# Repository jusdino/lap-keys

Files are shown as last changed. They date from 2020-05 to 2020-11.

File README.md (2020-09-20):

# lap-keys
A keyboard design that allows hands to naturally rest on the lap, while using

## Overview
This is a design prototype in progress for a new keyboard that will hopefully fix some ergonomic issues with my desk at home. Namely, I'm sick of keeping my hands up on a desk all day. I'd much rather let them relax on my lap while I work. Nothing I can find for commercially available (or other build-your-own) keyboard/mouse units seem to fit the bill.

## Prototypes
**Split Sixty Wedge**
- This is the first prototype I'm working on that is intended to be 'lap-friendly'. It should receive the custom PCBs I've designed to each include 5 switches in a column and a header that sticks out the top to allow for hand-wiring the key matrix between columns. This prototype is designed to be a simple 5x12 rectilinear split keyboard with each half arranged into a forward-pointing wedge. This configuration should get your wrists into a sensible orientation while typing either on a desk or your lap. It also includes a trackball, to help reduce the need for a dedicated pointing device. I'm calling this first prototype the **split sixty wedge**:
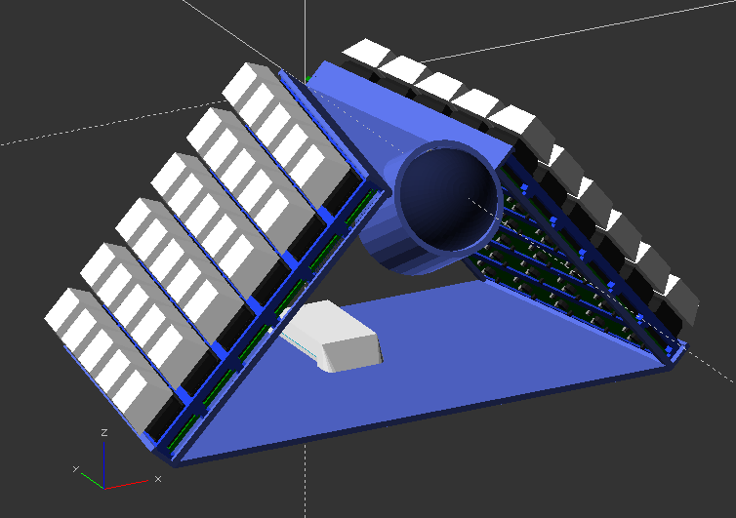
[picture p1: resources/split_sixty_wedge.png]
split sixty wedge


## Prints
The prints section of this repo consists of [OpenScad](https://www.openscad.org/) modules for any prototyping I'm doing and some that allow for quick definition of a keyboard with little more than the coordinates of where you want keys to be located. I've thrown together some *brain_storming* layouts with just coordinates that still produced a part that was reasonably printable, if not polished-looking. 

Some of the OpenScad modules include:

- Any prototypes I'm currently working on
- A rough mock-up of a CherryMX switch:
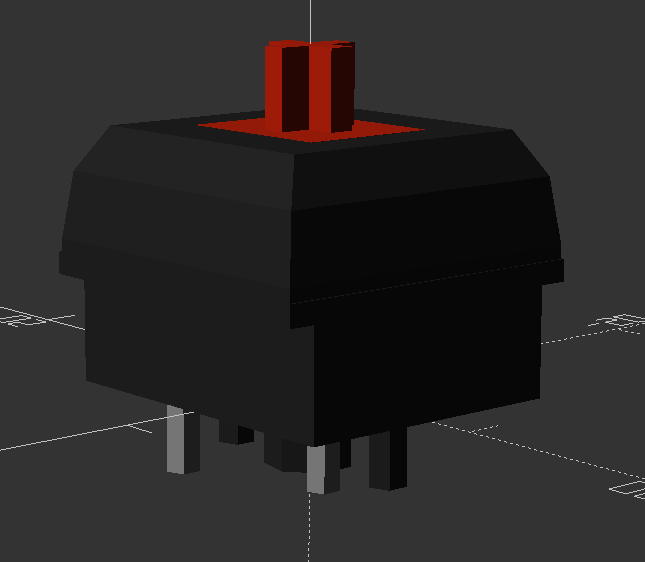
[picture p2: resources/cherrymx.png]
cherrymx switch


**Brain storming modules** that can be used for quick brain storming of layout ideas and can potentially be printed out and hand-wired:
- Sockets to fit the CherryMX switch:
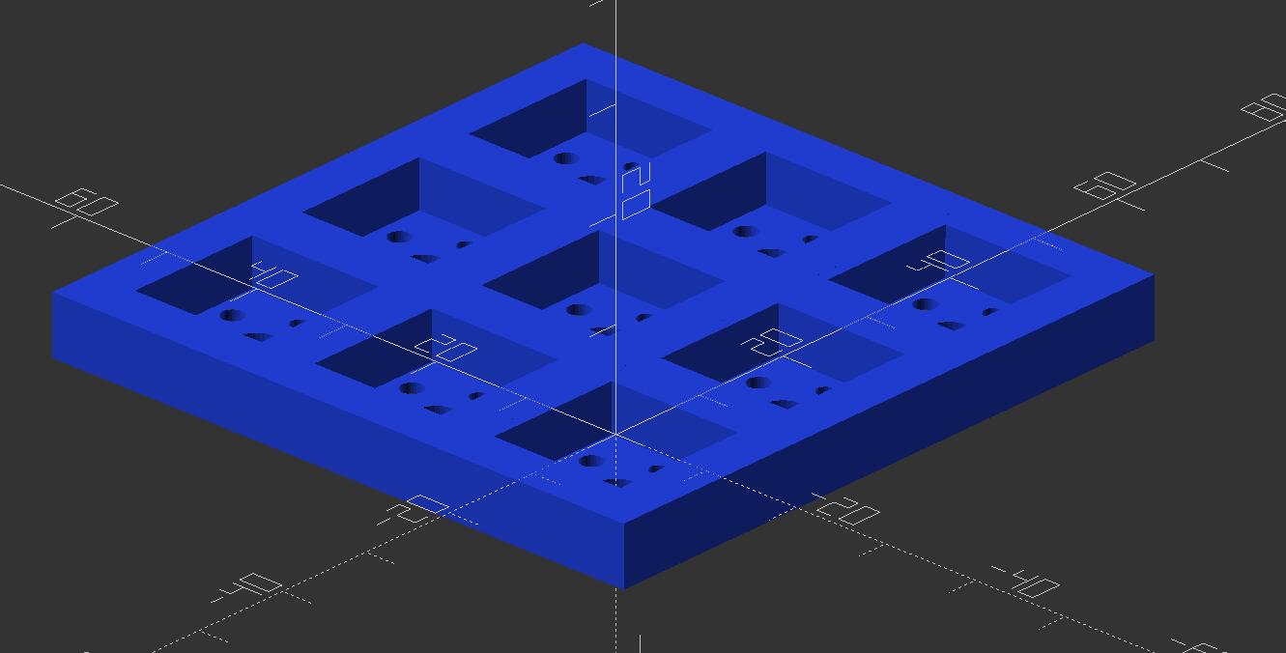
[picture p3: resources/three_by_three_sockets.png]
cherrymx socket


- A base to hold the sockets with space underneath for wiring:
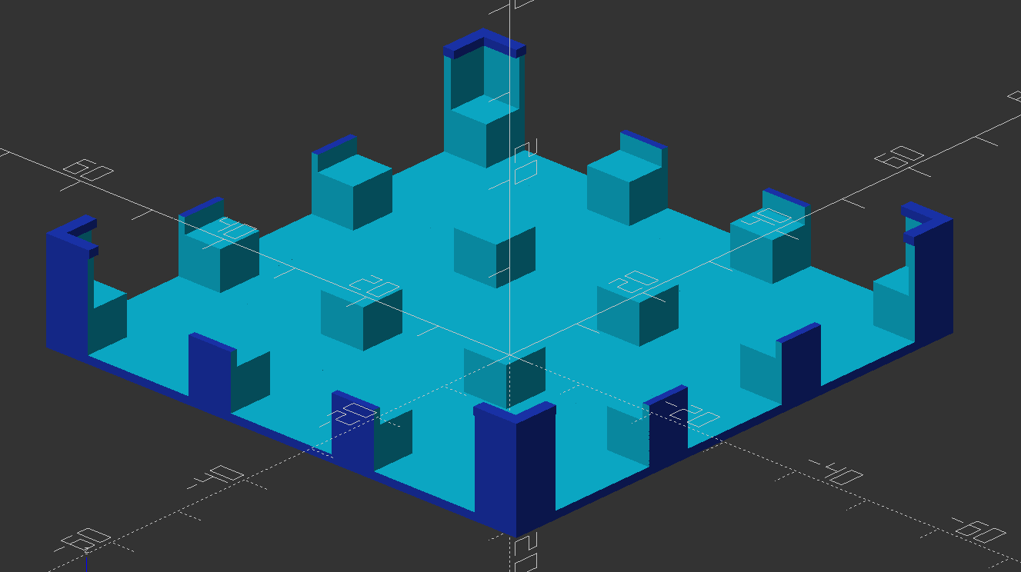
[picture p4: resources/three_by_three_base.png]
cherrymx base


- Some utility modules that can take a set of coordinates and translate them into the start of a workable keyboard:
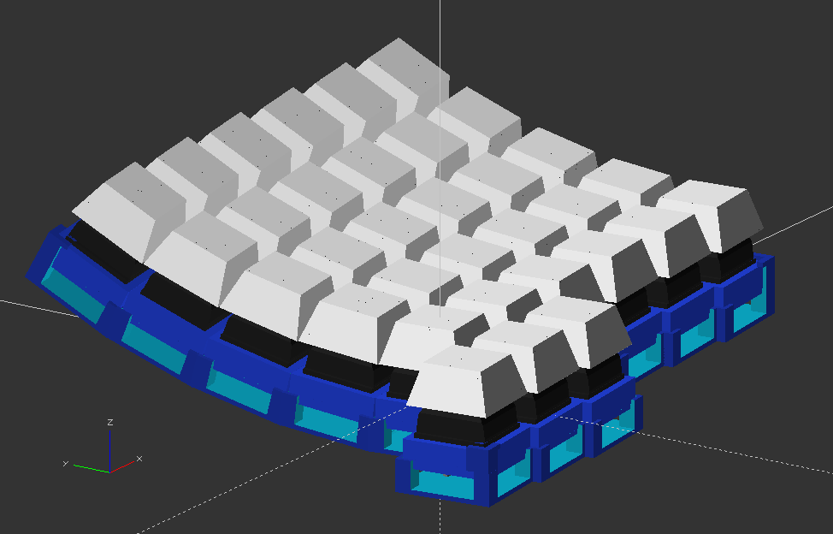
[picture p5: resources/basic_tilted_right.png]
tilted ortho


## Firmware
The firmware section of this repo contains MicroController Unit firmware I've designed to run on the MCU that drives the keyboard prototypes. These firmwares use the [QMK firmware](https://qmk.fm/) as their base.

## PCBs
The pcbs section of the repo contains KiCad PCB design files for any PCBs I design as part of this project

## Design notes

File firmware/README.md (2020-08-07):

# Keyboard Firmware

This firmware has been developed to use the [QMK Framework](https://docs.qmk.fm/#/) to program the MicroController Unit (MCU) that drives the keyboards in this repo. To use these firmware versions, copy (or softlink) the named keyboard directories into the QMK repository under `keyboards` and use them as described in the QMK documentation.

Keyboard firmwares:

## lap_keys
This firmware will drive the 60-key (5x12) keyboards in this project. The versions are:
- **v0.1**:
  Written for an [Elite-C MCU](https://keeb.io/products/elite-c-low-profile-version-usb-c-pro-micro-replacement-atmega32u4). Just keys. Very basic firmware with the keymap I worked out for the **split-sixty-percent** board.
- **v0.2**:
  Written for an [Elite-C MCU](https://keeb.io/products/elite-c-low-profile-version-usb-c-pro-micro-replacement-atmega32u4). Introduces the driver for the PMW3360 sensor used for a trackball.
- **v0.3**:
  Written for a [Proton-C MCU](https://qmk.fm/proton-c/). Same features as v0.2.

## 3_by_3
Firmware to test out a quick numpad-like prototype for learning purposes

## right_sixty_percent
Firmware to test out half of a sixty-percent keyboard

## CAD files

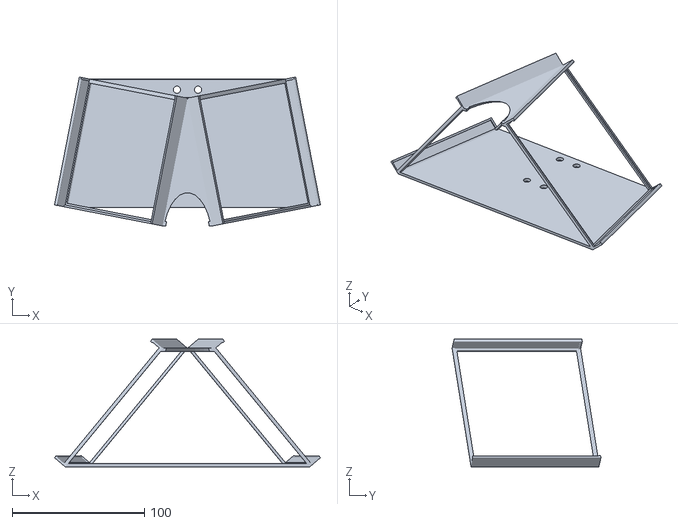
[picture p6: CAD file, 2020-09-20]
prints/outputs/split_sixty_wedge_base.stl
201.2 x 112.6 x 96.4

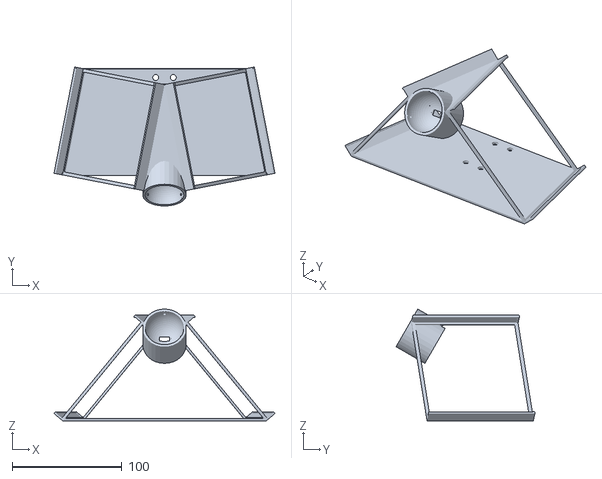
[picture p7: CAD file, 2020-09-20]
prints/outputs/split_sixty_wedge_base_w_trackball.stl
201.2 x 126.5 x 101.9

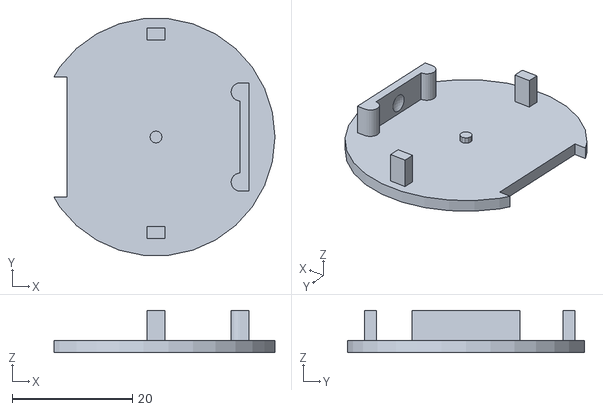
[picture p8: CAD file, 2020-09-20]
prints/outputs/trackball_mount_backing.stl
36.8 x 39.4 x 6.99

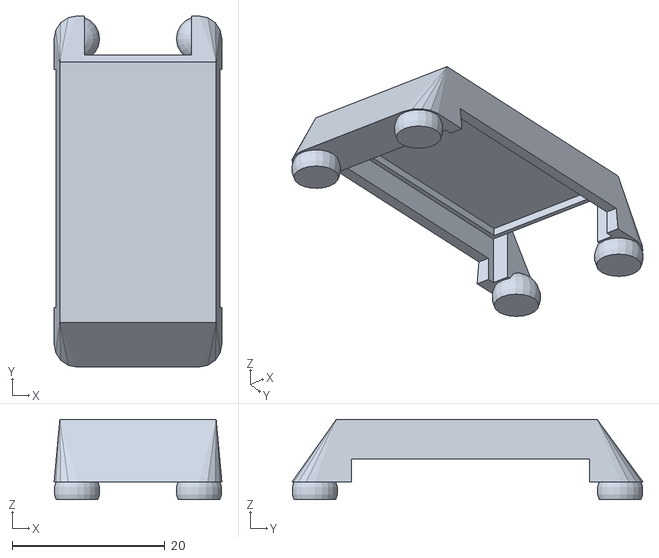
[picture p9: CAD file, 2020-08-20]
prints/outputs/split_sixty_wedge_elite_c_mount_top.stl
22.0 x 46.0 x 10.5

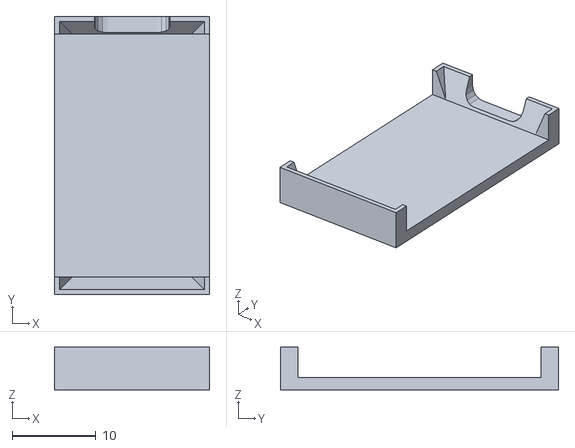
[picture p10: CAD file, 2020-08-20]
prints/outputs/split_sixty_wedge_elite_c_mount_bottom.stl
18.5 x 33.2 x 5.10

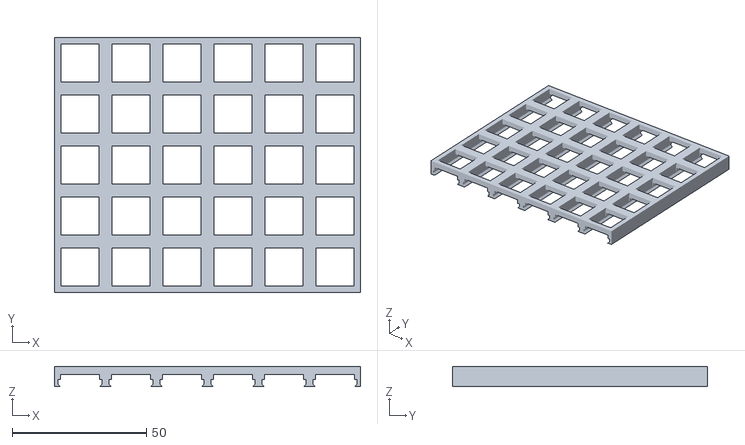
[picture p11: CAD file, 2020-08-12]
prints/outputs/split_sixty_wedge_plate.stl
114.0 x 95.0 x 7.60

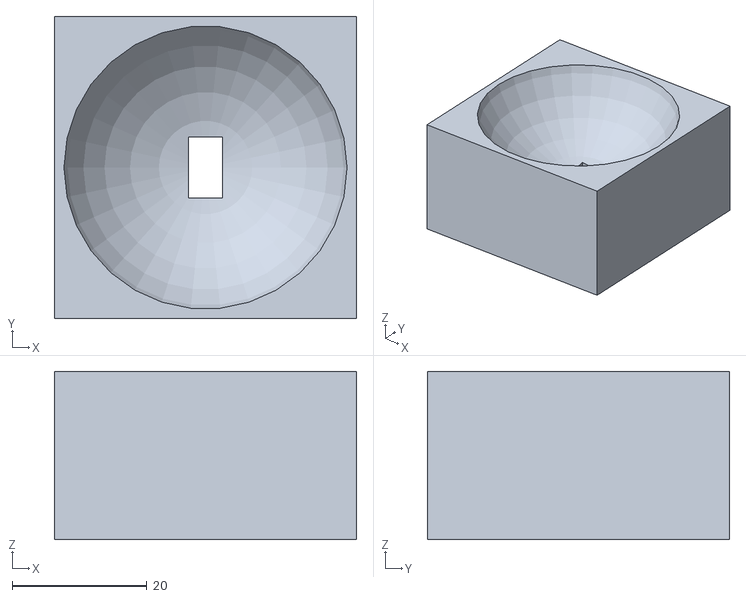
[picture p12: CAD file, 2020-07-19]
prints/outputs/track_stand.stl
44.8 x 44.8 x 24.9

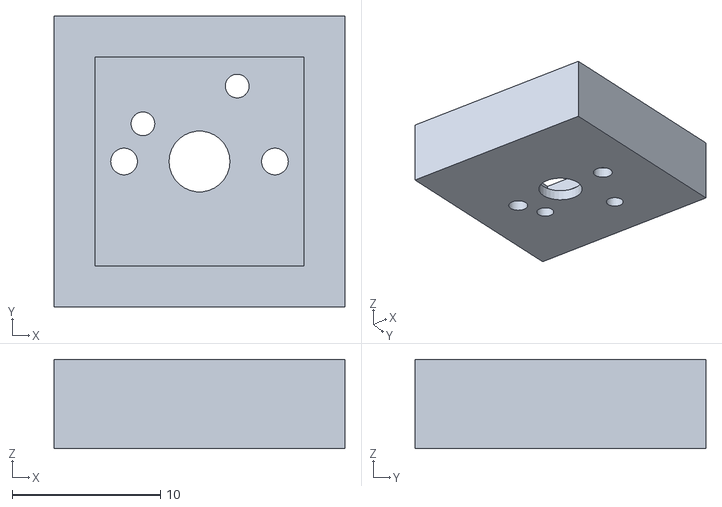
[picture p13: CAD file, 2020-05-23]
prints/outputs/cherrymx_socket.stl
19.6 x 19.6 x 6.00

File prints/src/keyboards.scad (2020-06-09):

include <switches.scad>;
include <sockets.scad>;
include <keycaps.scad>;
include <abstractions.scad>;
include <bases.scad>;

flat_ortho_grid(
  x_count=6,
  y_count=5,
  spacing=19,
  sockets=true,
  pcb_pins=true);

module sixty_percent(pcb_pins=false) {
  flat_ortho_grid(12, 5, pcb_pins);
}

module split_sixty_percent(pcb_pins=false) {
  flat_ortho_grid(6, 5, pcb_pins);
}

module three_by_three(pcb_pins=false) {
  flat_ortho_grid(3, 3, keys_and_caps=true, sockets=true, base=true, pcb_pins=pcb_pins);
}

module basic_ortholinear_right(pcb_pins=false) {
  spacing = 20;
  coords = [
    [0, 0, 0], [1, 0, 0], [2, 0, 0], [0, 1, 0], [0, 2, 0], [0, 3, 0], [0, 4, 0],
    [1, 1, 0], [2, 1, 0], [3, 1, 0], [4, 1, 0], [5, 1, 0], [6, 1, 0],
    [1, 2, 0], [2, 2, 0], [3, 2, 0], [4, 2, 0], [5, 2, 0], [6, 2, 0],
    [1, 3, 0], [2, 3, 0], [3, 3, 0], [4, 3, 0], [5, 3, 0], [6, 3, 0],
    [1, 4, 0], [2, 4, 0], [3, 4, 0], [4, 4, 0], [5, 4, 0], [6, 4, 0],
  ];

  dimensions = spacing * coords;

  map_over_xyz(dimensions) {
    keycap_1u();
    cherrymx(pcb_pins);
    cherrymx_socket(pcb_pins);
  }
  difference() {
    map_over_xyz(dimensions) {
      cherrymx_base_positive();
    }
    map_over_xyz(dimensions) {
      cherrymx_base_negative();
    }
  }
}

module basic_tilted_right(pcb_pins=false) {
  key_spacing = 20;
  curve_x_rad = 150;
  arc_length = key_spacing;
  dphi = (360*arc_length)/(2*PI*curve_x_rad);
  function y_from_phi(phi) = sin(phi)*curve_x_rad;
  function z_from_phi(phi) = curve_x_rad * (1 - cos(phi));
  function dx_from_phi(phi) = 2*phi/dphi;
  theta = atan(2/key_spacing);
  coords = [
  // X                                  Y                   Z                   PHI,    THETA
    [0,                                 -key_spacing,       0,                  0,      theta],
    [key_spacing,                       -key_spacing,       0,                  0,      theta],
    [0*key_spacing-dx_from_phi(0),      y_from_phi(0),      z_from_phi(0),      0,      theta],
    [1*key_spacing-dx_from_phi(0),      y_from_phi(0),      z_from_phi(0),      0,      theta],
    [2*key_spacing-dx_from_phi(0),      y_from_phi(0),      z_from_phi(0),      0,      theta],
    [3*key_spacing-dx_from_phi(0),      y_from_phi(0),      z_from_phi(0),      0,      theta],
    [4*key_spacing-dx_from_phi(0),      y_from_phi(0),      z_from_phi(0),      0,      theta],
    [5*key_spacing-dx_from_phi(0),      y_from_phi(0),      z_from_phi(0),      0,      theta],
    [6*key_spacing-dx_from_phi(0),      y_from_phi(0),      z_from_phi(0),      0,      theta],
    [0*key_spacing-dx_from_phi(1*dphi), y_from_phi(1*dphi), z_from_phi(1*dphi), 1*dphi, theta],
    [1*key_spacing-dx_from_phi(1*dphi), y_from_phi(1*dphi), z_from_phi(1*dphi), 1*dphi, theta],
    [2*key_spacing-dx_from_phi(1*dphi), y_from_phi(1*dphi), z_from_phi(1*dphi), 1*dphi, theta],
    [3*key_spacing-dx_from_phi(1*dphi), y_from_phi(1*dphi), z_from_phi(1*dphi), 1*dphi, theta],
    [4*key_spacing-dx_from_phi(1*dphi), y_from_phi(1*dphi), z_from_phi(1*dphi), 1*dphi, theta],
    [5*key_spacing-dx_from_phi(1*dphi), y_from_phi(1*dphi), z_from_phi(1*dphi), 1*dphi, theta],
    [6*key_spacing-dx_from_phi(1*dphi), y_from_phi(1*dphi), z_from_phi(1*dphi), 1*dphi, theta],
    [0*key_spacing-dx_from_phi(2*dphi), y_from_phi(2*dphi), z_from_phi(2*dphi), 2*dphi, theta],
    [1*key_spacing-dx_from_phi(2*dphi), y_from_phi(2*dphi), z_from_phi(2*dphi), 2*dphi, theta],
    [2*key_spacing-dx_from_phi(2*dphi), y_from_phi(2*dphi), z_from_phi(2*dphi), 2*dphi, theta],
    [3*key_spacing-dx_from_phi(2*dphi), y_from_phi(2*dphi), z_from_phi(2*dphi), 2*dphi, theta],
    [4*key_spacing-dx_from_phi(2*dphi), y_from_phi(2*dphi), z_from_phi(2*dphi), 2*dphi, theta],
    [5*key_spacing-dx_from_phi(2*dphi), y_from_phi(2*dphi), z_from_phi(2*dphi), 2*dphi, theta],
    [6*key_spacing-dx_from_phi(2*dphi), y_from_phi(2*dphi), z_from_phi(2*dphi), 2*dphi, theta],
    [0*key_spacing-dx_from_phi(3*dphi), y_from_phi(3*dphi), z_from_phi(3*dphi), 3*dphi, theta],
    [1*key_spacing-dx_from_phi(3*dphi), y_from_phi(3*dphi), z_from_phi(3*dphi), 3*dphi, theta],
    [2*key_spacing-dx_from_phi(3*dphi), y_from_phi(3*dphi), z_from_phi(3*dphi), 3*dphi, theta],
    [3*key_spacing-dx_from_phi(3*dphi), y_from_phi(3*dphi), z_from_phi(3*dphi), 3*dphi, theta],
    [4*key_spacing-dx_from_phi(3*dphi), y_from_phi(3*dphi), z_from_phi(3*dphi), 3*dphi, theta],
    [5*key_spacing-dx_from_phi(3*dphi), y_from_phi(3*dphi), z_from_phi(3*dphi), 3*dphi, theta],
    [6*key_spacing-dx_from_phi(3*dphi), y_from_phi(3*dphi), z_from_phi(3*dphi), 3*dphi, theta],
  ];
  corners = [
  // X                                  Y                   Z                   PHI,    THETA
    [0,                                 -key_spacing,       0,                  0,      theta],
    [0*key_spacing-dx_from_phi(3*dphi), y_from_phi(3*dphi), z_from_phi(3*dphi), 3*dphi, theta],
    [6*key_spacing-dx_from_phi(3*dphi), y_from_phi(3*dphi), z_from_phi(3*dphi), 3*dphi, theta],
    [6*key_spacing-dx_from_phi(0),      y_from_phi(0),      z_from_phi(0),      0,      theta],
  ];

  map_over_xyzpt(coords) {
    keycap_1u();
    cherrymx(pcb_pins);
    cherrymx_socket(pcb_pins);
  }
  difference() {
    union() {
      map_over_xyzpt(coords) {
        cherrymx_base_positive();
      }
      map_over_xyzpt([corners[0]]) cherrymx_base_corner_clip(minus_x_minus_y=true);
      map_over_xyzpt([corners[1]]) cherrymx_base_corner_clip(minus_x_plus_y=true);
      map_over_xyzpt([corners[2]]) cherrymx_base_corner_clip(plus_x_plus_y=true);
      map_over_xyzpt([corners[3]]) cherrymx_base_corner_clip(plus_x_minus_y=true);
    }
    map_over_xyzpt(coords) {
      cherrymx_base_negative();
    }
  }
}

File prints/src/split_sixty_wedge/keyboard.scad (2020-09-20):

// KEYBOARD: Split Sixty Wedge
// First step towards a more functional design: Adding a PCB, reducing space for hand-wires.

// MULTI-MODULE VARS
// General inputs
keys_and_caps=true;
plates=true;
pcbs=true;

mcu_mount=true;
mcu=true;

trackball_mount=true;
trackball=true;
sensor=true;
bearings=true;

keyboard_x_count = 6;
keyboard_y_count = 5;
keyboard_switch_spacing = 19;
keyboard_y_rotation = 50;
keyboard_z_rotation = 11;

include <switch_plate.scad>;

// switch_base attributes
switch_base_thickness = 1.5;
switch_base_bottom_width = 3;
switch_base_tolerance_dy = 0.5;

switch_base_dx = switch_plate_dx + 2*switch_base_thickness;
switch_base_dy = switch_plate_dy + 2*switch_base_thickness + switch_base_tolerance_dy;
switch_base_dz = switch_base_thickness;

// Keyboard attributes
keyboard_base_color = [80/255, 100/255, 200/255];
keyboard_snap_hole_rad = 3;
keyboard_bottom_connector_bottom_z = -switch_base_dx * sin(keyboard_y_rotation);
keyboard_bottom_connector_top_z = -(switch_base_dx-switch_base_bottom_width) * sin(keyboard_y_rotation);
keyboard_bottom_connector_dz = keyboard_bottom_connector_top_z - keyboard_bottom_connector_bottom_z;
keyboard_bottom_connector_front_y = switch_base_dx * cos(keyboard_y_rotation) * sin(keyboard_z_rotation);

keyboard_mcu_connectors_shift_dy = 5 + keyboard_snap_hole_rad;
keyboard_mcu_connectors_dx = 10 + 2*keyboard_snap_hole_rad;
keyboard_mcu_connectors_dy = 34 + 2*keyboard_snap_hole_rad;

keyboard_top_dx = switch_base_dy*sin(keyboard_z_rotation)*2;
keyboard_top_dy = switch_base_dy*cos(keyboard_z_rotation);
keyboard_top_dz = switch_base_bottom_width * sin(keyboard_y_rotation);

include <trackball_mount.scad>;
include <elite_c_mount.scad>;

keyboard();
module keyboard() {
  e = 0.01;

  x_count = keyboard_x_count;
  y_count = keyboard_y_count;
  switch_spacing = keyboard_switch_spacing;

  base_color = keyboard_base_color;
  base_thickness = switch_base_thickness;
  base_bottom_width = switch_base_bottom_width;
  base_dx = switch_base_dx;
  base_dy = switch_base_dy;

  y_rotation = keyboard_y_rotation;
  z_rotation = keyboard_z_rotation;

  bottom_connector_bottom_z = keyboard_bottom_connector_bottom_z;
  bottom_connector_top_z = keyboard_bottom_connector_top_z;
  bottom_connector_dz = keyboard_bottom_connector_dz;
  bottom_connector_front_y = keyboard_bottom_connector_front_y;

  snap_hole_rad = keyboard_snap_hole_rad;
  mcu_connectors_shift_dy = keyboard_mcu_connectors_shift_dy;
  mcu_connectors_dx = keyboard_mcu_connectors_dx;
  mcu_connectors_dy = keyboard_mcu_connectors_dy;

  wedge_mirror() {
    switch_base();
  }
  color(base_color) {
    // Top connector plate
    difference() {
      hull() {
        wedge_mirror() {
          translate([0, -base_dy, 0]) {
            cube([base_bottom_width, base_dy, e]);
          }
        }
      }
      translate([0, -keyboard_top_dy, 0]) {
        trackball_mount_cutout();
      }
    }
    // Bottom connector plate
    difference() {
      hull() {
        wedge_mirror() {
          translate([base_dx-base_bottom_width, -base_dy, 0]) {
            cube([base_bottom_width, base_dy, e]);
          }
        }
      }
      // MCU connector snap holes
      translate([0, bottom_connector_front_y, bottom_connector_bottom_z+bottom_connector_dz/2]) {
        translate([0, -mcu_connectors_shift_dy, 0]) {
          translate([mcu_connectors_dx/2, 0, 0]) sphere(r=snap_hole_rad, $fn=20);
          translate([-mcu_connectors_dx/2, 0, 0]) sphere(r=snap_hole_rad, $fn=20);
          translate([mcu_connectors_dx/2, -mcu_connectors_dy, 0]) sphere(r=snap_hole_rad, $fn=20);
          translate([-mcu_connectors_dx/2, -mcu_connectors_dy, 0]) sphere(r=snap_hole_rad, $fn=20);
        }
      }
    }
  }
  if (trackball_mount) {
    translate([0, -keyboard_top_dy, 0]) {
      trackball_mount();
    }
  }
  if (mcu_mount) {
    translate([0, bottom_connector_front_y, bottom_connector_top_z]) {
      elite_c_mount(mcu);
    }
  }

  
  module wedge_mirror() {
    wedge_rotate() {
      children();
    }
    mirror([1, 0, 0]) {
      wedge_rotate() {
        children();
      }
    }
  }

  module wedge_rotate() {
    rotate([0, y_rotation, z_rotation]) {
      children();
    }
  }

  //switch_base();
  module switch_base() {
    e = 0.01;

    x_count = keyboard_x_count;
    y_count = keyboard_y_count;
    switch_spacing = keyboard_switch_spacing;
    y_rotation = keyboard_y_rotation;
    z_rotation = keyboard_z_rotation;

    pcb_dz = switch_column_plate_pcb_dz;
    pcb_holder_overreach_dz = switch_column_plate_pcb_holder_overreach_dz;

    plate_dz = switch_plate_dz;
    plate_dx = switch_plate_dx;
    plate_dy = switch_plate_dy;

    base_thickness = switch_base_thickness;
    base_dx = switch_base_dx;
    base_dy = switch_base_dy;
    base_dz = switch_base_dz;
    base_bottom_width = switch_base_bottom_width;

    color(base_color) {
      translate([0, -base_dy, 0]) {
        difference() {
          union() {
            // Main frame
            cube([base_dx, base_dy, base_dz]);
            cube([base_thickness, base_dy, plate_dz+base_thickness*2]);
            cube([base_dx, base_thickness, (plate_dz+base_thickness)/4]);
            translate([base_dx-base_thickness, 0, 0]) {
              cube([base_thickness, base_dy, plate_dz+base_thickness*2]);
            }
            // Overreach tabs
            translate([base_thickness, 0, plate_dz+1.5*base_thickness]) {
              rotate([-90, 0, 0]) {
                cylinder(h=base_dy, d=base_thickness, $fn=8);
                translate([plate_dx, 0, 0]) {
                  cylinder(h=base_dy, d=base_thickness, $fn=8);
                }
              }
            }
          }
          // Bottom subtraction
          translate([base_bottom_width, base_bottom_width, -e]) {
            cube([base_dx-2*base_bottom_width, base_dy-base_bottom_width*2, base_thickness+2*e]);
          }
        }
      }
      // Front
      translate([0, -base_thickness, ]) {
        cube([base_dx, base_thickness, base_dz+pcb_holder_overreach_dz/2]);
        cube([base_thickness*1.5, base_thickness, plate_dz+base_thickness*2]);
        translate([base_dx-base_thickness*1.5, 0, 0]) {
          cube([base_thickness*1.5, base_thickness, plate_dz+base_thickness*2]);
        }
      }
    }
    if (plates) {
      translate([base_thickness, -base_thickness, base_dz+2*e]) {
        switch_plate();
      }
    }

  }
}

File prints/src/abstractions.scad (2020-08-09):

// Utility module to quickly map a module over coordinates or some other pre-defined abstractions
//
// map_over_coordinates([[0, 0, 0], [20, 20, 20]]) {
//   cherrymx();
// }

include <components/switches.scad>;
include <components/sockets.scad>;
include <components/keycaps.scad>;

module map_over_xyz(coordinates) {
  for (i=coordinates) {
    translate(i) {
      children();
    }
  }
}

module map_over_xyzpt(coordinates) {
  for (i=coordinates) {
    translate([i[0], i[1], i[2]]) {
      rotate([i[3], 0, 0]) {
        rotate([0, 0, i[4]]) {
          children();
        }
      }
    }
  }
}

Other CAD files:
prints/src/bases.scad
prints/src/brain_storming/bases.scad
prints/src/brain_storming/brainstorms.scad
prints/src/brain_storming/split_sixty_wedge.scad
prints/src/components/PMW3360.scad
prints/src/components/connectors.scad
prints/src/components/keycaps.scad
prints/src/components/mcus.scad
prints/src/components/sockets.scad
prints/src/components/switches.scad
prints/src/misc/track_stand.scad
prints/src/sockets.scad
prints/src/split_sixty_wedge/elite_c_mount.scad
prints/src/split_sixty_wedge/switch_plate.scad
prints/src/split_sixty_wedge/trackball_mount.scad

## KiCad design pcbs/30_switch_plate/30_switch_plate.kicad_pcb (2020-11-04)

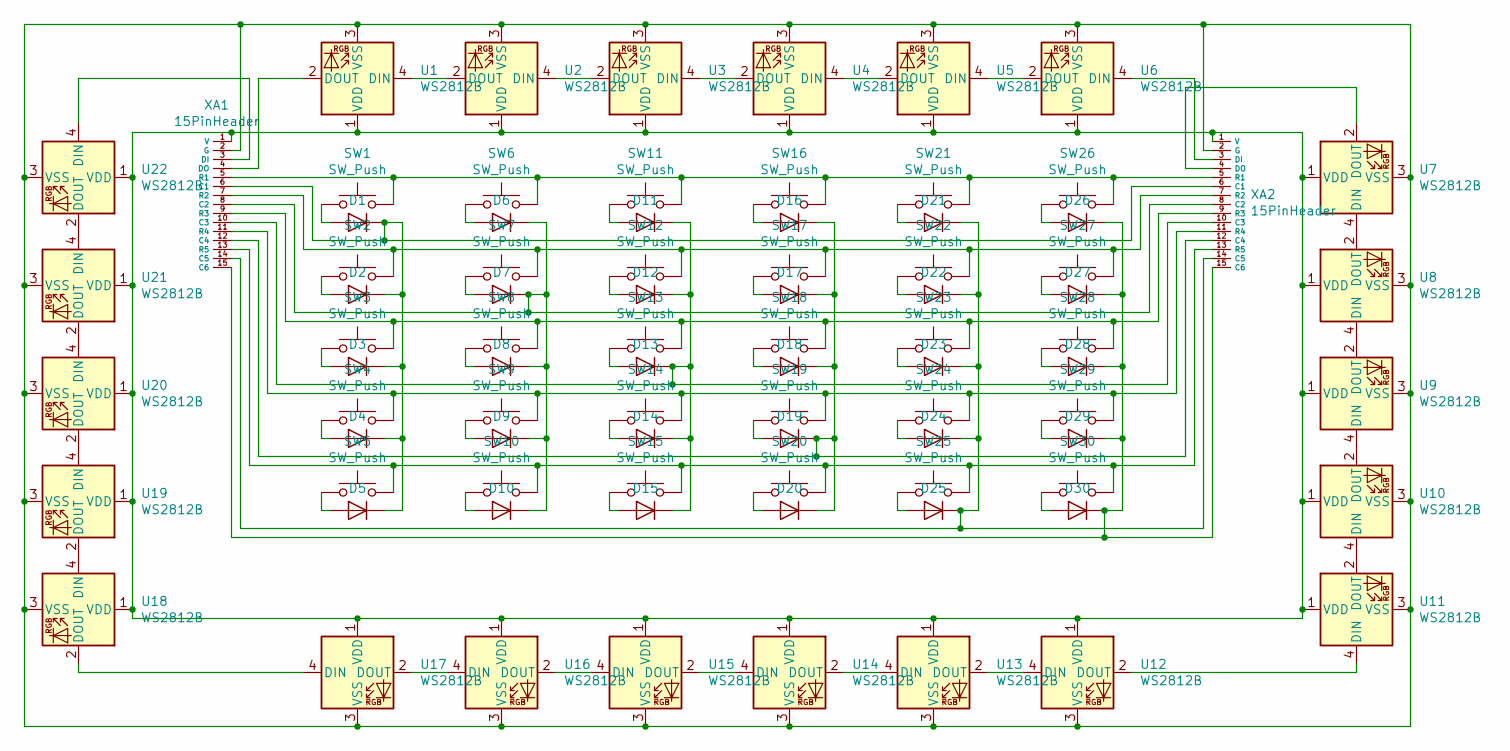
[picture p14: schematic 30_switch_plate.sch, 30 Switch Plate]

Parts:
D1, D2, D3, D4, D5, D6, D7, D8, D9, D10, D11, D12, D13, D14, D15, D16, D17, D18, D19, D20, D21, D22, D23, D24, D25, D26, D27, D28, D29, D30: GPDiode; SOD-723; LCSC C308742
SW1, SW2, SW3, SW4, SW5, SW6, SW7, SW8, SW9, SW10, SW11, SW12, SW13, SW14, SW15, SW16, SW17, SW18, SW19, SW20, SW21, SW22, SW23, SW24, SW25, SW26, SW27, SW28, SW29, SW30: SW_Push; SW_Cherry_MX_1.00u_PCB_JF
U1, U2, U3, U4, U5, U6, U7, U8, U9, U10, U11, U12, U13, U14, U15, U16, U17, U18, U19, U20, U21, U22: WS2812B; LED_WS2812B_PLCC4_5.0x5.0mm_P3.2mm; LCSC C114586
XA1, XA2: 15PinHeader

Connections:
unnamed: D1.1 (K), D2.1 (K), D3.1 (K), D4.1 (K), D5.1 (K), XA1.6 (C1), XA2.6 (C1)
unnamed: D1.2 (A), SW1.1
unnamed: D2.2 (A), SW2.1
unnamed: D3.2 (A), SW3.1
unnamed: D4.2 (A), SW4.1
unnamed: D5.2 (A), SW5.1
unnamed: D6.2 (A), SW6.1
unnamed: D7.2 (A), SW7.1
unnamed: D8.2 (A), SW8.1
unnamed: D9.2 (A), SW9.1
unnamed: D6.1 (K), D7.1 (K), D8.1 (K), D9.1 (K), D10.1 (K), XA1.8 (C2), XA2.8 (C2)
unnamed: D10.2 (A), SW10.1
unnamed: D11.1 (K), D12.1 (K), D13.1 (K), D14.1 (K), D15.1 (K), XA1.10 (C3), XA2.10 (C3)
unnamed: D11.2 (A), SW11.1
unnamed: D12.2 (A), SW12.1
unnamed: D13.2 (A), SW13.1
unnamed: D14.2 (A), SW14.1
unnamed: D15.2 (A), SW15.1
unnamed: D16.1 (K), D17.1 (K), D18.1 (K), D19.1 (K), D20.1 (K), XA1.12 (C4), XA2.12 (C4)
unnamed: D16.2 (A), SW16.1
unnamed: D17.2 (A), SW17.1
unnamed: D18.2 (A), SW18.1
unnamed: D19.2 (A), SW19.1
unnamed: D20.2 (A), SW20.1
unnamed: D21.1 (K), D22.1 (K), D23.1 (K), D24.1 (K), D25.1 (K), XA1.14 (C5), XA2.14 (C5)
unnamed: D21.2 (A), SW21.1
unnamed: D22.2 (A), SW22.1
unnamed: D23.2 (A), SW23.1
unnamed: D24.2 (A), SW24.1
unnamed: D25.2 (A), SW25.1
unnamed: D26.1 (K), D27.1 (K), D28.1 (K), D29.1 (K), D30.1 (K), XA1.15 (C6), XA2.15 (C6)
unnamed: D26.2 (A), SW26.1
unnamed: D27.2 (A), SW27.1
unnamed: D28.2 (A), SW28.1
unnamed: D29.2 (A), SW29.1
unnamed: D30.2 (A), SW30.1
unnamed: SW1.2, SW6.2, SW11.2, SW16.2, SW21.2, SW26.2, XA1.5 (R1), XA2.5 (R1)
unnamed: SW5.2, SW10.2, SW15.2, SW20.2, SW25.2, SW30.2, XA1.13 (R5), XA2.13 (R5)
unnamed: SW2.2, SW7.2, SW12.2, SW17.2, SW22.2, SW27.2, XA1.7 (R2), XA2.7 (R2)
unnamed: SW3.2, SW8.2, SW13.2, SW18.2, SW23.2, SW28.2, XA1.9 (R3), XA2.9 (R3)
unnamed: SW4.2, SW9.2, SW14.2, SW19.2, SW24.2, SW29.2, XA1.11 (R4), XA2.11 (R4)
unnamed: U1.1 (VDD), U2.1 (VDD), U3.1 (VDD), U4.1 (VDD), U5.1 (VDD), U6.1 (VDD), U7.1 (VDD), U8.1 (VDD), U9.1 (VDD), U10.1 (VDD), U11.1 (VDD), U12.1 (VDD), U13.1 (VDD), U14.1 (VDD), U15.1 (VDD), U16.1 (VDD), U17.1 (VDD), U18.1 (VDD), U19.1 (VDD), U20.1 (VDD), U21.1 (VDD), U22.1 (VDD), XA1.1 (V), XA2.1 (V)
unnamed: U1.2 (DOUT), XA1.4 (DO)
unnamed: U1.3 (VSS), U2.3 (VSS), U3.3 (VSS), U4.3 (VSS), U5.3 (VSS), U6.3 (VSS), U7.3 (VSS), U8.3 (VSS), U9.3 (VSS), U10.3 (VSS), U11.3 (VSS), U12.3 (VSS), U13.3 (VSS), U14.3 (VSS), U15.3 (VSS), U16.3 (VSS), U17.3 (VSS), U18.3 (VSS), U19.3 (VSS), U20.3 (VSS), U21.3 (VSS), U22.3 (VSS), XA1.2 (G), XA2.2 (G)
unnamed: U1.4 (DIN), U2.2 (DOUT)
unnamed: U2.4 (DIN), U3.2 (DOUT)
unnamed: U3.4 (DIN), U4.2 (DOUT)
unnamed: U4.4 (DIN), U5.2 (DOUT)
unnamed: U5.4 (DIN), U6.2 (DOUT)
unnamed: U6.4 (DIN), XA2.3 (DI)
unnamed: U7.2 (DOUT), XA2.4 (DO)
unnamed: U7.4 (DIN), U8.2 (DOUT)
unnamed: U8.4 (DIN), U9.2 (DOUT)
unnamed: U9.4 (DIN), U10.2 (DOUT)
unnamed: U10.4 (DIN), U11.2 (DOUT)
unnamed: U11.4 (DIN), U12.2 (DOUT)
unnamed: U12.4 (DIN), U13.2 (DOUT)
unnamed: U13.4 (DIN), U14.2 (DOUT)
unnamed: U14.4 (DIN), U15.2 (DOUT)
unnamed: U15.4 (DIN), U16.2 (DOUT)
unnamed: U16.4 (DIN), U17.2 (DOUT)
unnamed: U17.4 (DIN), U18.2 (DOUT)
unnamed: U18.4 (DIN), U19.2 (DOUT)
unnamed: U19.4 (DIN), U20.2 (DOUT)
unnamed: U20.4 (DIN), U21.2 (DOUT)
unnamed: U21.4 (DIN), U22.2 (DOUT)
unnamed: U22.4 (DIN), XA1.3 (DI)

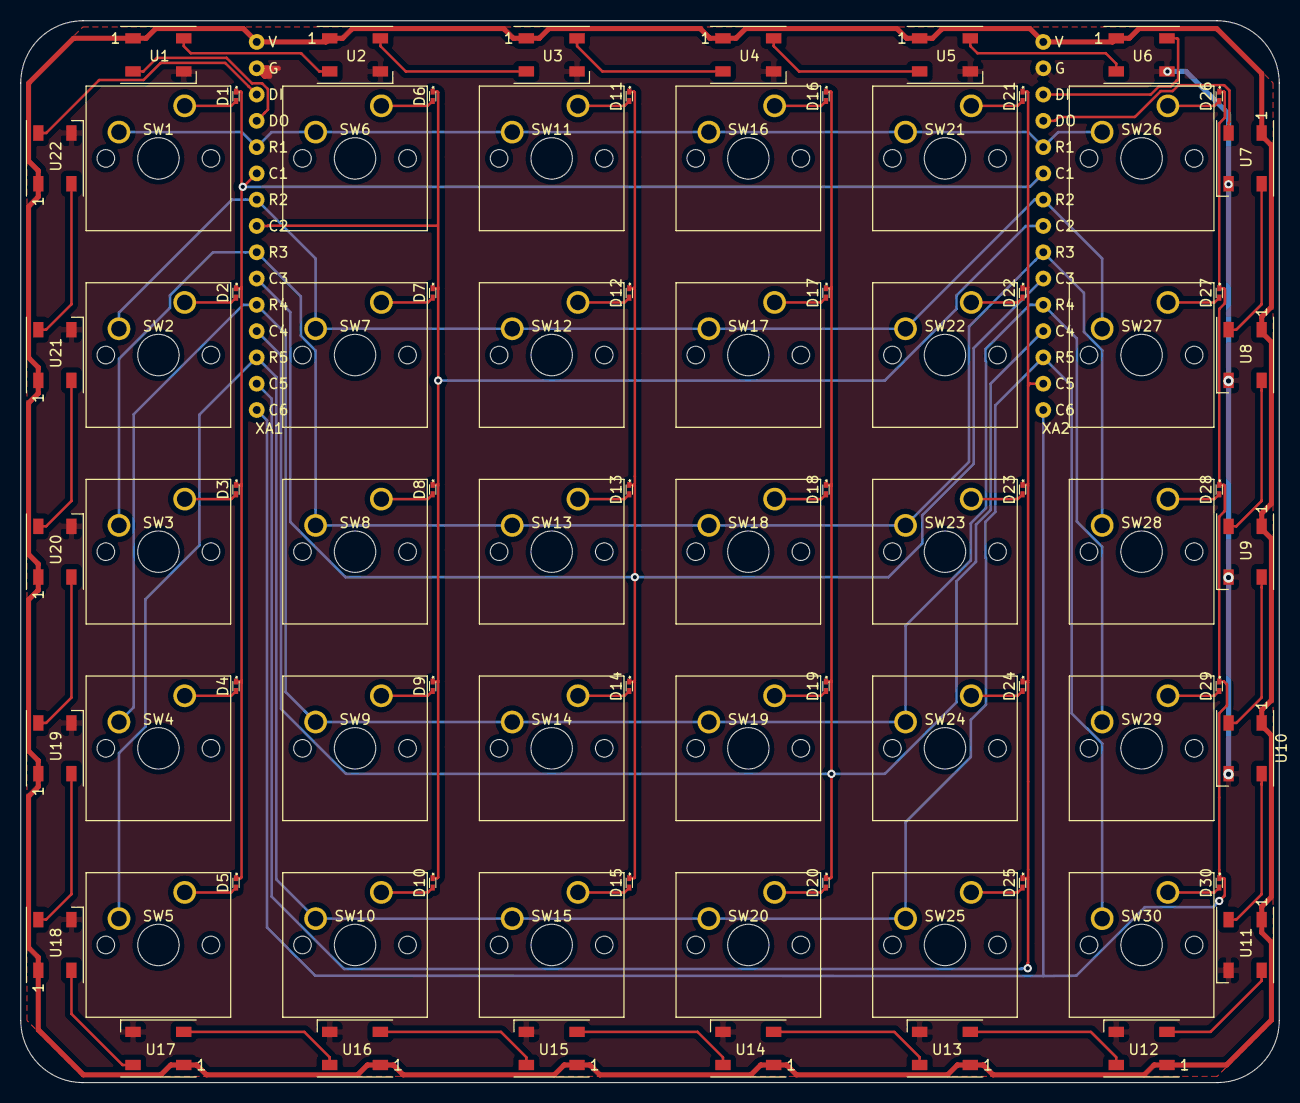
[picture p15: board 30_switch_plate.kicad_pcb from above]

Board: 2 copper layers, 121.6 x 102.6 mm, 84 parts (0 on the bottom side), 67 nets.

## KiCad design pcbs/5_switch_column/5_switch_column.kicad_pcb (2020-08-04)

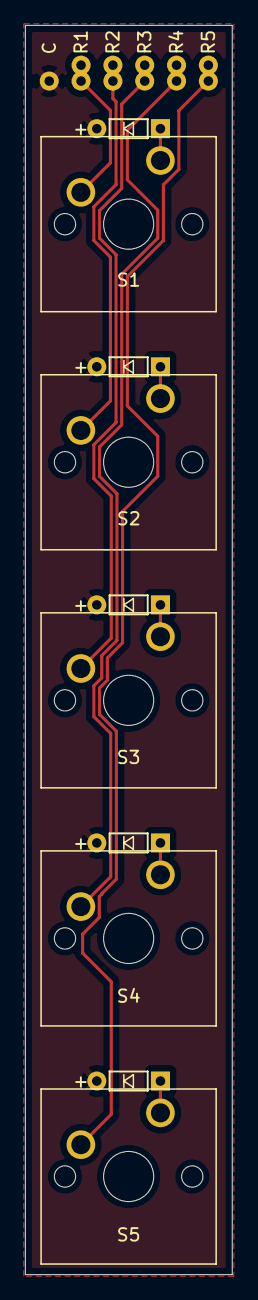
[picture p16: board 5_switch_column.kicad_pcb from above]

Board: 2 copper layers, 16.5 x 99.7 mm, 6 parts (0 on the bottom side), 11 nets.

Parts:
S1, S2, S3, S4, S5: CherryMXDiode; SW_Cherry_MX_1.00u_PCB
U1: 6PinHeader

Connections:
unnamed: S1.1, S1.3
unnamed: S1.2, U1.2
unnamed: S1.4, S2.4, S3.4, S4.4, S5.4, U1.1
unnamed: S2.1, S2.3
unnamed: S2.2, U1.3
unnamed: S3.1, S3.3
unnamed: S3.2, U1.4
unnamed: S4.1, S4.3
unnamed: S4.2, U1.5
unnamed: S5.1, S5.3
unnamed: S5.2, U1.6

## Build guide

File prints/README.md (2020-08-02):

# Keyboard prints
The [OpenSCAD](https://www.openscad.org/) designs here are 3D-Printed parts for building of the designed keyboards
. `src/` contains the `*.scad` source files and `outputs/` contains some of the exported `*.stl` files generated for key parts.

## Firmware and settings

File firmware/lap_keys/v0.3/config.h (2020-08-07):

#pragma once

#include "config_common.h"

/* USB Device descriptor parameter */
#define VENDOR_ID       0x6a75
#define PRODUCT_ID      0x0000
#define DEVICE_VER      0x0000
#define MANUFACTURER    Jusdino
#define PRODUCT         prototype
#define DESCRIPTION     Jusdinos working keyboard space

/* key matrix size */
#define MATRIX_ROWS 5
#define MATRIX_COLS 12

/* mine PCB default pin-out */
#define MATRIX_ROW_PINS { B12, A15, A8, A7, A6 }
#define MATRIX_COL_PINS { A2, A1, A0, B8, B10, B11, A9, A10, B7, B6, B5, B4 }
#define UNUSED_PINS

/* COL2ROW or ROW2COL */
#define DIODE_DIRECTION ROW2COL

/* OPTIMIZATIONS */
#define NO_ACTION_MACRO
#define NO_ACTION_FUNCTION

/* PMW3360 */
/*#define SPI_DEBUG*/
#define PMW_SS B9
#define CPI 1600
#define SPI_DIVISOR 4

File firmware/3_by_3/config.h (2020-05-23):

#ifndef CONFIG_H
#define CONFIG_H

#include "config_common.h"

/* USB Device descriptor parameter */
#define VENDOR_ID       0xFEED
#define PRODUCT_ID      0x0007
#define DEVICE_VER 		0x0001
#define MANUFACTURER    Jusdino
#define PRODUCT         prototype
#define DESCRIPTION     Jusdinos working keyboard space

/* key matrix size */
#define MATRIX_ROWS 3
#define MATRIX_COLS 3

/* mine PCB default pin-out */
#define MATRIX_ROW_PINS { D0, D1, D2 }
#define MATRIX_COL_PINS { B2, B1, B0 }
#define UNUSED_PINS

/* ws2812 RGB LED */
#define RGB_DI_PIN F7

#define RGBLED_NUM 1    // Number of LEDs

/* COL2ROW or ROW2COL */
#define DIODE_DIRECTION ROW2COL

#define TAPPING_TERM 200

#endif

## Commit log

2020-05-17 Add a couple starting files
    [switches.scad]
2020-05-17 Add some layouts
    [grid_frame.scad, map.scad, sockets.scad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]
2020-05-17 Refine some geometry details
    [grid_frame.scad, map.scad, sockets.scad]
2020-05-21 Add a quick-and-dirty base
    [grid_frame.scad, keycaps.scad, misc.scad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]
2020-05-23 Add some outputs, firmware, updated README notes
    [9key_base.stl, 9key_sockets.stl, cherrymx_socket.stl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]
2020-05-31 Add split sixty wedge
    [9key_base.stl, 9key_sockets.stl, bases.scad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]
2020-06-09 Update split sixty wedge
    [abstractions.scad, keyboards.scad, map.scad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]
2020-06-10 Drop duplicate files
    [grid_frame.scad, keycaps.scad, map.scad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]
2020-07-19 Super broken but commiting anyway
    [PMW3360.c, config.h]
2020-07-28 Make SPI work (#2)
    * comms good, SROM bad
    * Holy crap, it works!
    * Drop debug key
    * Make it all work!
2020-07-28 Qmk spi master driver (#3)
    * Clean up some debugging
    * Update to use spi_master.h driver
    * Clean up dead code
2020-08-04 Add KiCAD PCB files
    [5_switch_column-B_Cu.gbl, 5_switch_column-B_Mask.gbs, 5_switch_column-B_SilkS.gbo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]
2020-08-07 Add a broken Proton-C firmware
    [PMW3360.c, config.h]
2020-08-09 Split_Sixty_Wedge w/ PCB in prog
    [abstractions.scad, bases.scad, brainstorms.scad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]
2020-08-09 Clean up these stinking projec files _again_
    [5_switch_column.sch]
2020-08-10 Add beginings of the base
    [split_sixty_wedge.scad]
2020-08-12 Finish ss wedge, cleanup
    [9key_base.stl, 9key_sockets.stl, brainstorms.scad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]
2020-08-14 Revisions after first print
    [split_sixty_wedge.scad, split_sixty_wedge_base.stl]
2020-08-16 Some variable/module organizing
    [split_sixty_wedge.scad]
2020-08-19 Begin mcu-mount design
    [mcus.scad, split_sixty_wedge.scad]
2020-08-20 Add Elite C mount
    [split_sixty_wedge.scad, split_sixty_wedge_elite_c_mount_bottom.stl, split_sixty_wedge_elite_c_mount_top.stl]
2020-08-30 Reorg, start trackball mount
    [PMW3360.scad, elite_c_mount.scad, keyboard.scad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]
2020-09-02 Attach trackball mount to kb base
    [connectors.scad, keyboard.scad, switch_plate.scad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]
2020-09-03 Add trackball mount backing
    [connectors.scad, keyboard.scad, trackball_mount.scad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]
2020-09-20 Revise trackball design to one that actually worked
    [keyboard.scad, split_sixty_wedge_base.stl, split_sixty_wedge_base_w_trackball.stl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]
2020-11-04 Add 30_switch_plate
    [30_switch_plate.kicad_pcb, 30_switch_plate.sch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]

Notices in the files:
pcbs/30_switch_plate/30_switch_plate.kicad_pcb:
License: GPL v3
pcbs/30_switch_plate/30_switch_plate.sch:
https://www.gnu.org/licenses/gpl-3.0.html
